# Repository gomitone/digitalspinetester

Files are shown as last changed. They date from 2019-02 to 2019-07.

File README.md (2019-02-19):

# digitalspinetester
Arrow digital spine tester powered by Arduino Nano compatible board.

The digital spine tester allows to weigh and calculate shaft spine.
It uses cheap components and it is made of few lines of code.
It uses well known libraries that are referenced in the code itself.
Also listed below.

The schema is in the dwg/dxf file but can be improved as also the overall design could be.

All the logic to obtain the main spine formula is reported in the excel file.
There is no comments but easy to understand.
The principle is to work on the opposite of the classic spine tester.
Usually (classic approach), we apply a weight of two pounds reading the shaft bending.
So the constant is the weight while the variable is the bending.
In the digital spine tester, the constant is the bending and the variable is the applied weight.

That's all...

The code and all the information are shared and freely usable for personal use and amusement.

Some commercial versions of the digital spine tester are available on the market.
If you need something more professional, I suggest to give to them a chance.
Even if this DIY version is cheap and precise. :-)

Please share your hints and, if possible, your version and improvements.

Credits:
Libraries referenced in the code:

OLED library for Oled
Universal 8bit Graphics Library (https://github.com/olikraus/u8g2/)

HX711 library for load cell amplifier
Bogde HX711 lib (https://github.com/bogde/HX711)

Button library 
Mathertel OneButtonlib (https://github.com/mathertel/OneButton)

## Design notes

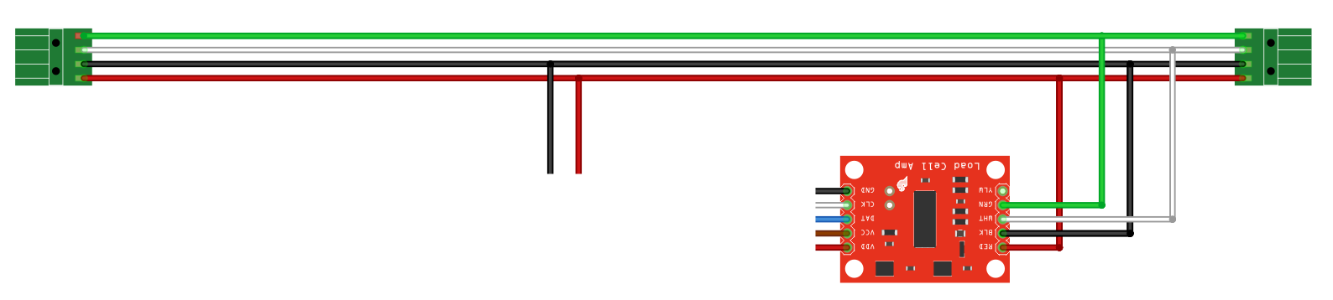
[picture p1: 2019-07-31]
TwoLoadCells.png

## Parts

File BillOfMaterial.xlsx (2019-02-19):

Component | Description | Link | Qty | Price | Total
 | HX711 Load Cell Amplifier | https://www.ebay.com/itm/Auto-Shieding-Weighing-Sensor-AD-Module-Dual-channel-24-bit-A-D-Conversion-HX711/311923139099 | 1 | 0.99 | $0.99
 | Load cell (2Kg) | https://www.ebay.com/itm/YZC-133-Mini-Scale-Electronic-Load-Cell-Weighing-Sensor-1-2-3-5-10-50Kg-NEW/172454812349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 | 2 | $2.66 | $5.32
 | Arduino Nano | https://www.ebay.com/itm/Mini-USB-Nano-V3-0-ATmega328-16M-5V-Micro-controller-CH340G-board-For-Arduino/201539955347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 | 1 | $3.45 | $3.45
 | Oled 128*32 (5v) | https://www.ebay.com/itm/0-91-128x32-IIC-I2C-Blue-OLED-LCD-Display-DIY-Module-DC3-3V-5V-For-PIC-Arduino/401234789687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 | 1 | $2.59 | $2.59
 | Push Button | https://www.ebay.com/itm/50pcs-6-6-7mm-Tactile-Push-Button-Switch-4pin-Tact-Switch-4P-DIP-for-Arduino/162212052435 | 3 | $1.85 | $5.55
 | PCB Board (7*9cm) | https://www.ebay.com/itm/5-10Pcs-PCB-Printed-Circuit-Board-Universal-Proto-Breadboard-For-DIY-Projects-8/163180975902 | 1 | $1.19 | $1.19
 | Pine board 82*7.5*2 cm | Home depot or other | 1 | $5.00 | $5.00
 | Hardware (screws, rubber feet, metal strips, etc.) | Home depot or other | various | $7.50 | $7.50
 |  |  |  | Total | $31.59

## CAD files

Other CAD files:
BoardSchema.dxf
BoardSchema.dwg

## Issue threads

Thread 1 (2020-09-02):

no matching function

PEHO70, 2020-09-02:
Hi
after check and compiling the digital_spine_tester.ino i got error message in Arduino IDE 1.8.13.
at line.................. **HX711 scale (DOUT, CLK);**

copied error message:

Digital_Spine_Tester:19:22: error: no matching function for call to 'HX711::HX711(int, int)'
 HX711 scale(DOUT, CLK);
                      ^
In file included from D:\TEMP\Dig_Spine\SW\Digital_Spine_Tester\Digital_Spine_Tester.ino:14:0:
C:\Users\_______\Documents\Arduino\libraries\HX711/HX711.h:22:3: note: candidate: HX711::HX711()
   HX711();
   ^~~~~
C:\Users\_______\Documents\Arduino\libraries\HX711/HX711.h:22:3: note:   candidate expects 0 arguments, 2 provided
C:\Users\_______\Documents\Arduino\libraries\HX711/HX711.h:19:7: note: candidate: constexpr HX711::HX711(const HX711&)
 class HX711
       ^~~~~
C:\Users\_______\Documents\Arduino\libraries\HX711/HX711.h:19:7: note:   candidate expects 1 argument, 2 provided
exit status 1
no matching function for call to 'HX711::HX711(int, int)'

Is there any idea what i did wrong ??

gomitone, 2020-09-02:
Hi,
did you installed all the provided libraries?

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

PEHO70, 2020-09-02:
Hi Roberto

yes, all linked libraries from the readme-file are installed

HX711, onebutton & u8g2..

BR

Peter

Gesendet: Mittwoch, 02. September 2020 um 10:16 Uhr
Von: "Roberto Di Pace" <notifications@github.com>
An: "gomitone/digitalspinetester" <digitalspinetester@noreply.github.com>
Cc: "Peter" <schon.mal@abwesend.de>, "Author" <author@noreply.github.com>
Betreff: Re: [gomitone/digitalspinetester] no matching function (#1)

Hi,
did you installed all the provided libraries?

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
—
You are receiving this because you authored the thread.
Reply to this email directly, view it on GitHub, or unsubscribe.

PEHO70, 2020-09-04:
Hi Roberto
solved this issue byself..

Please find part of the new code...

Deleted **(Dout, CLK)** after HX711 scale and add the initializing command to **setup (void)**....that´s it..

HX711 **scale;**

OneButton buttonTare(4, true);                    //Digital pin 3 for Tare button
OneButton buttonWeight(5, true);                  //Digital pin 4 for Weight button
OneButton buttonSpine(6, true);                   //Digital pin 5 for Spine button

float calibration_factor = 456;                   //Value calculated from calibration of digital scale. Standard values in grams
float baseWeight = 0.0;                           //To store shaft weight
float spineWeight = 0.0;                          //To store weight for spine measurement

U8G2_SSD1306_128X32_UNIVISION_F_HW_I2C u8g2(U8G2_R0); //Initialize the proper oled. See library sample for the correct one.

void setup(void) {
  **scale.begin(DOUT, CLK);**
  u8g2.begin();                                   //Initialize display
  buttonTare.attachClick(click1);                 //-----------------------------------------------
  buttonTare.attachLongPressStop(pressStop1);     //Attach different..
  buttonWeight.attachClick(click2);               //..buttons actions
  buttonSpine.attachClick(click3);                //-----------------------------------------------
}

Feel free to updated your .ino file

BR
PEter

gomitone, 2020-09-13:
Thanks Peter,
not sure why the code as-is doesn’t work.
But I’m happy you found a solution.
Regards
Roberto

Sent from Mail for Windows 10

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

Closed 2020-09-04.

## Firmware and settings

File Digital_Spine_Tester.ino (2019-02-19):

/*
  Credits:
  OLED library for Oled
    Universal 8bit Graphics Library (https://github.com/olikraus/u8g2/)
  HX711 library for load cell amplifier
    Bogde HX711 lib (https://github.com/bogde/HX711)
  Button library 
    Mathertel OneButtonlib (https://github.com/mathertel/OneButton)
*/
#include <Arduino.h>
#include <U8g2lib.h>
#include <SPI.h>
#include <OneButton.h>
#include "HX711.h"

#define DOUT  2                                   //Pin 2 and 3 to connect HX711 load cell amplifier
#define CLK  3                                    //

HX711 scale(DOUT, CLK);

OneButton buttonTare(4, true);                    //Digital pin 3 for Tare button
OneButton buttonWeight(5, true);                  //Digital pin 4 for Weight button
OneButton buttonSpine(6, true);                   //Digital pin 5 for Spine button

float calibration_factor = 456;                   //Value calculated from calibration of digital scale. Standard values in grams
float baseWeight = 0.0;                           //To store shaft weight
float spineWeight = 0.0;                          //To store weight for spine measurement

U8G2_SSD1306_128X32_UNIVISION_F_HW_I2C u8g2(U8G2_R0); //Initialize the proper oled. See library sample for the correct one.

void setup(void) {
  u8g2.begin();                                   //Initialize display
  buttonTare.attachClick(click1);                 //-----------------------------------------------
  buttonTare.attachLongPressStop(pressStop1);     //Attach different..
  buttonWeight.attachClick(click2);               //..buttons actions
  buttonSpine.attachClick(click3);                //-----------------------------------------------
}

void loop(void) {
  scale.set_scale(calibration_factor);            //Adjust to the calibration factor (here 456)
  buttonTare.tick();                              //-----------------------------------------------
  buttonWeight.tick();                            //Read button state
  buttonSpine.tick();                             //-----------------------------------------------
}

void click1() {                                   //Event simple click for TARE before spine (button 3)
  scale.tare();                                   //Tare
  u8g2.clearBuffer();                             //Clear the internal buffer
  u8g2.setFont(u8g2_font_logisoso28_tr);          //Choose a font before position cursor and print
  u8g2.setCursor(0, 32);                          //Set cursor position
  u8g2.print(0.0, 2);                             //Print 0.00 with two decimals
  u8g2.setFont(u8g2_font_t0_16_tr);               //Change font
  u8g2.setCursor(85, 24);                         //Change cursor position
  u8g2.print("But3>");                            //Print But3 to indicate to click the third button
  u8g2.sendBuffer();                              //Transfer internal memory to the display
}

void pressStop1() {                               //Event end of long press to tare before weight shaft
  scale.tare();                                   
  u8g2.clearBuffer();                             
  u8g2.setFont(u8g2_font_logisoso28_tr);          
  u8g2.setCursor(0, 32);                          
  u8g2.print(0.0, 2);                             
  u8g2.setFont(u8g2_font_t0_16_tr);               
  u8g2.setCursor(85, 24);                         
  u8g2.print("But2>");                            //Print But2 to indicate to click the second button
  u8g2.sendBuffer();                              
}

void click2() {                                   //Event click for Weight
  baseWeight=scale.get_units(10);                 //Average of ten readings 
  u8g2.clearBuffer();                             
  u8g2.setFont(u8g2_font_logisoso28_tr);   
  u8g2.setCursor(0, 32);                   
  u8g2.print(baseWeight, 2);                      //Print shaft weight with two decimals
  u8g2.setFont(u8g2_font_t0_16_tr);
  u8g2.setCursor(85, 16);
  u8g2.print(baseWeight, 2);                      //Print resume of the shaft weight
  u8g2.sendBuffer();                       
}
void click3() {                                   //Event click for Spine
  float localWeight=0.0;                          //Variable to store the weight for spine calc
  localWeight=scale.get_units(10);                
  spineWeight=(((localWeight/1000.00)-0.521980143)*60/1.565940428)+20;      //Formula to calculate the spine. It depends from maximum bending
  u8g2.clearBuffer();                      
  u8g2.setFont(u8g2_font_logisoso28_tr);   
  u8g2.setCursor(0, 32);                   
  u8g2.print(spineWeight, 2);                     //Print shaft spine with two decimals
  u8g2.setFont(u8g2_font_t0_16_tr);
  u8g2.setCursor(85, 16);
  u8g2.print(baseWeight, 2);                      //Print resume of the shaft weight
  u8g2.setFont(u8g2_font_t0_16_tr);
  u8g2.setCursor(85, 32);
  u8g2.print(spineWeight, 2);                     //Print resume of the shaft spine
  u8g2.sendBuffer();                       
}
